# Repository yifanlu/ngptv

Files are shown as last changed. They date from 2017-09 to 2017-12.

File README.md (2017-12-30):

ngptv
=====
This is an attempt at making an HDMI adapter for the Vita. It does not work 
because the ADV7533 does not support the auto clock stopping that the Vita uses 
to save battery on the MIPI DSI clock. There are two ways of getting it to 
work.

1. Replace the ADV7533 with another part that supports MIPI clock going from 
HS to LP mode when the data lanes are not in use. There are no other DSI to 
HDMI part, but you might get away with stacking a DSI to eDP and eDP to HDMI 
for example. Another way is to use a FPGA and convert the signals manually.
2. Creating some custom part to "filter" the stopped clock to a continuous 
clock. There does not appear to be any off-the-shelf part that does this and 
I've tried looking into re-purposing jitter correctors but they don't work 
because they average out the clock signals instead of locking on to the highest 
frequency.

Both are too much work for me to consider doing, so I will leave this non-
working project as is. Included are two designs. First is ngptv, which is 
supposed to be a small board that fits inside the Vita. Due to the design 
constraints of the ADV7533 (small pitch BGA) which requires > 6 layers and the 
small size requirement of all components, it does not seem feasible for me to 
prototype (too expensive and I don't have the right equipment to assemble).
Additionally, the ADV7533 is a NDA part that requires a HDMI license to buy.

The second design is ngptv lite which is designed to connect directly to a 
[B-LCDAD-HDMI](http://www.st.com/en/development-tools/b-lcdad-hdmi1.html) 
daughterboard. This $30 board contains a ADV7533 and was originally designed to 
work with a ST evaluation board. We instead connect it to the ngptv lite which 
has a microcontroller to interface with ADV7533 as well as a redriver for MIPI 
DSI. Using a 
[FFTP-07-D-03.85-01-N](https://www.samtec.com/products/fftp-07-d-03.85-01-n) 
cable, this connects to a breakout board placed inside the Vita that brings in 
the MIPI DSI signals from the exposed testpoints. The first version lacked the 
redriver, which seemed to still work (to the extent that it works if you 
manually set the Vita's MIPI clock to not use LP mode, which breaks the on 
screen video).

These designs are provided as-is under CC 4.0.

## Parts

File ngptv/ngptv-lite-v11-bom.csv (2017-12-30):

Part | Value | Device | Package | Description
C1 | 100nf | CERAMIC-100NF-50V-10%-X7R(0603) | C0603 | 302010138
C2 | 100nf | CERAMIC-100NF-50V-10%-X7R(0603) | C0603 | 302010138
C3 | 100nf | CERAMIC-100NF-50V-10%-X7R(0603) | C0603 | 302010138
C4 | 1uf | CERAMIC-1UF-25V-10%-X7R(0603) | C0603 | 302010139
C5 | 1uf | CERAMIC-1UF-25V-10%-X7R(0603) | C0603 | 302010139
C6 | 1uf | CERAMIC-1UF-25V-10%-X7R(0603) | C0603 | 302010139
C7 | 200nF | CERAMIC-220NF-25V-10%-X7R(0603) | C0603 | 302010073
C8 | 100nf | CERAMIC-100NF-50V-10%-X7R(0603) | C0603 | 302010138
C9 | 100nf | CERAMIC-100NF-50V-10%-X7R(0603) | C0603 | 302010138
C10 | 100nf | CERAMIC-100NF-50V-10%-X7R(0603) | C0603 | 302010138
D1 | BLUE-0603 | SMD-LED-CLEAR-BLUE(0603) | LED-0603 | 304090045
J1 | FTSH-107-XX-XXX-D | FTSH-107-XX-XXX-D | FTSH-107-XX-XXX-D | 0.050X0.050" CL THROUGH HOLE TERMINAL STRIP ASSEMBLY,14PINS."
J2 | FTSH-107-XX-XXX-D | FTSH-107-XX-XXX-D | FTSH-107-XX-XXX-D | 0.050X0.050" CL THROUGH HOLE TERMINAL STRIP ASSEMBLY,14PINS."
J3 | QSH-030-01-X-D-A | QSH-030-01-X-D-A | QSH-030-01-X-D-A | HIGH SPEED SOCKET STRIP, .5mm PITCH, 60 PINS.
J4 |  | PINHD-2X3/90 | 2X03/90 | PIN HEADER
L1 | 2500R-50MA | SMD-FERRITE-BEAD-2500R-50MA(0603) | L0603 | 303030020
R1 | 2K | SMD-RES-2K-5%-1/10W(0603) | R0603 | 301010298
R2 | 2K | SMD-RES-2K-5%-1/10W(0603) | R0603 | 301010113
R3 | 2K | SMD-RES-2K-5%-1/10W(0603) | R0603 | 301010113
R4 | 200K | SMD-RES-200K-5%-1/10W(0603) | R0603 | 301010212
R5 | 2K | SMD-RES-2K-5%-1/10W(0603) | R0603 | 301010113
R6 | 2K | SMD-RES-2K-5%-1/10W(0603) | R0603 | 301010113
U1 | AP7312-1833W6-7 | AP7312 | SOT95P280X145-6N
U2 | SN75DPHY440SS | SN75DPHY440SS | RHR0028A_NV
U3 | ATTINY24A-SSU | ATTINY24A-SSU | SOIC127P600X175-14N | 8-bit Microcontroller with In-System Programmable Flash
U4 | PCA9306_DCT_8 | PCA9306_DCT_8 | DCT8
X1 | ZX62D-B-5PA8 | ZX62D-B-5PA8 | ZX62D-B-5PA8 | Micro USB Type B Connector - Standard, Shell Through Hole

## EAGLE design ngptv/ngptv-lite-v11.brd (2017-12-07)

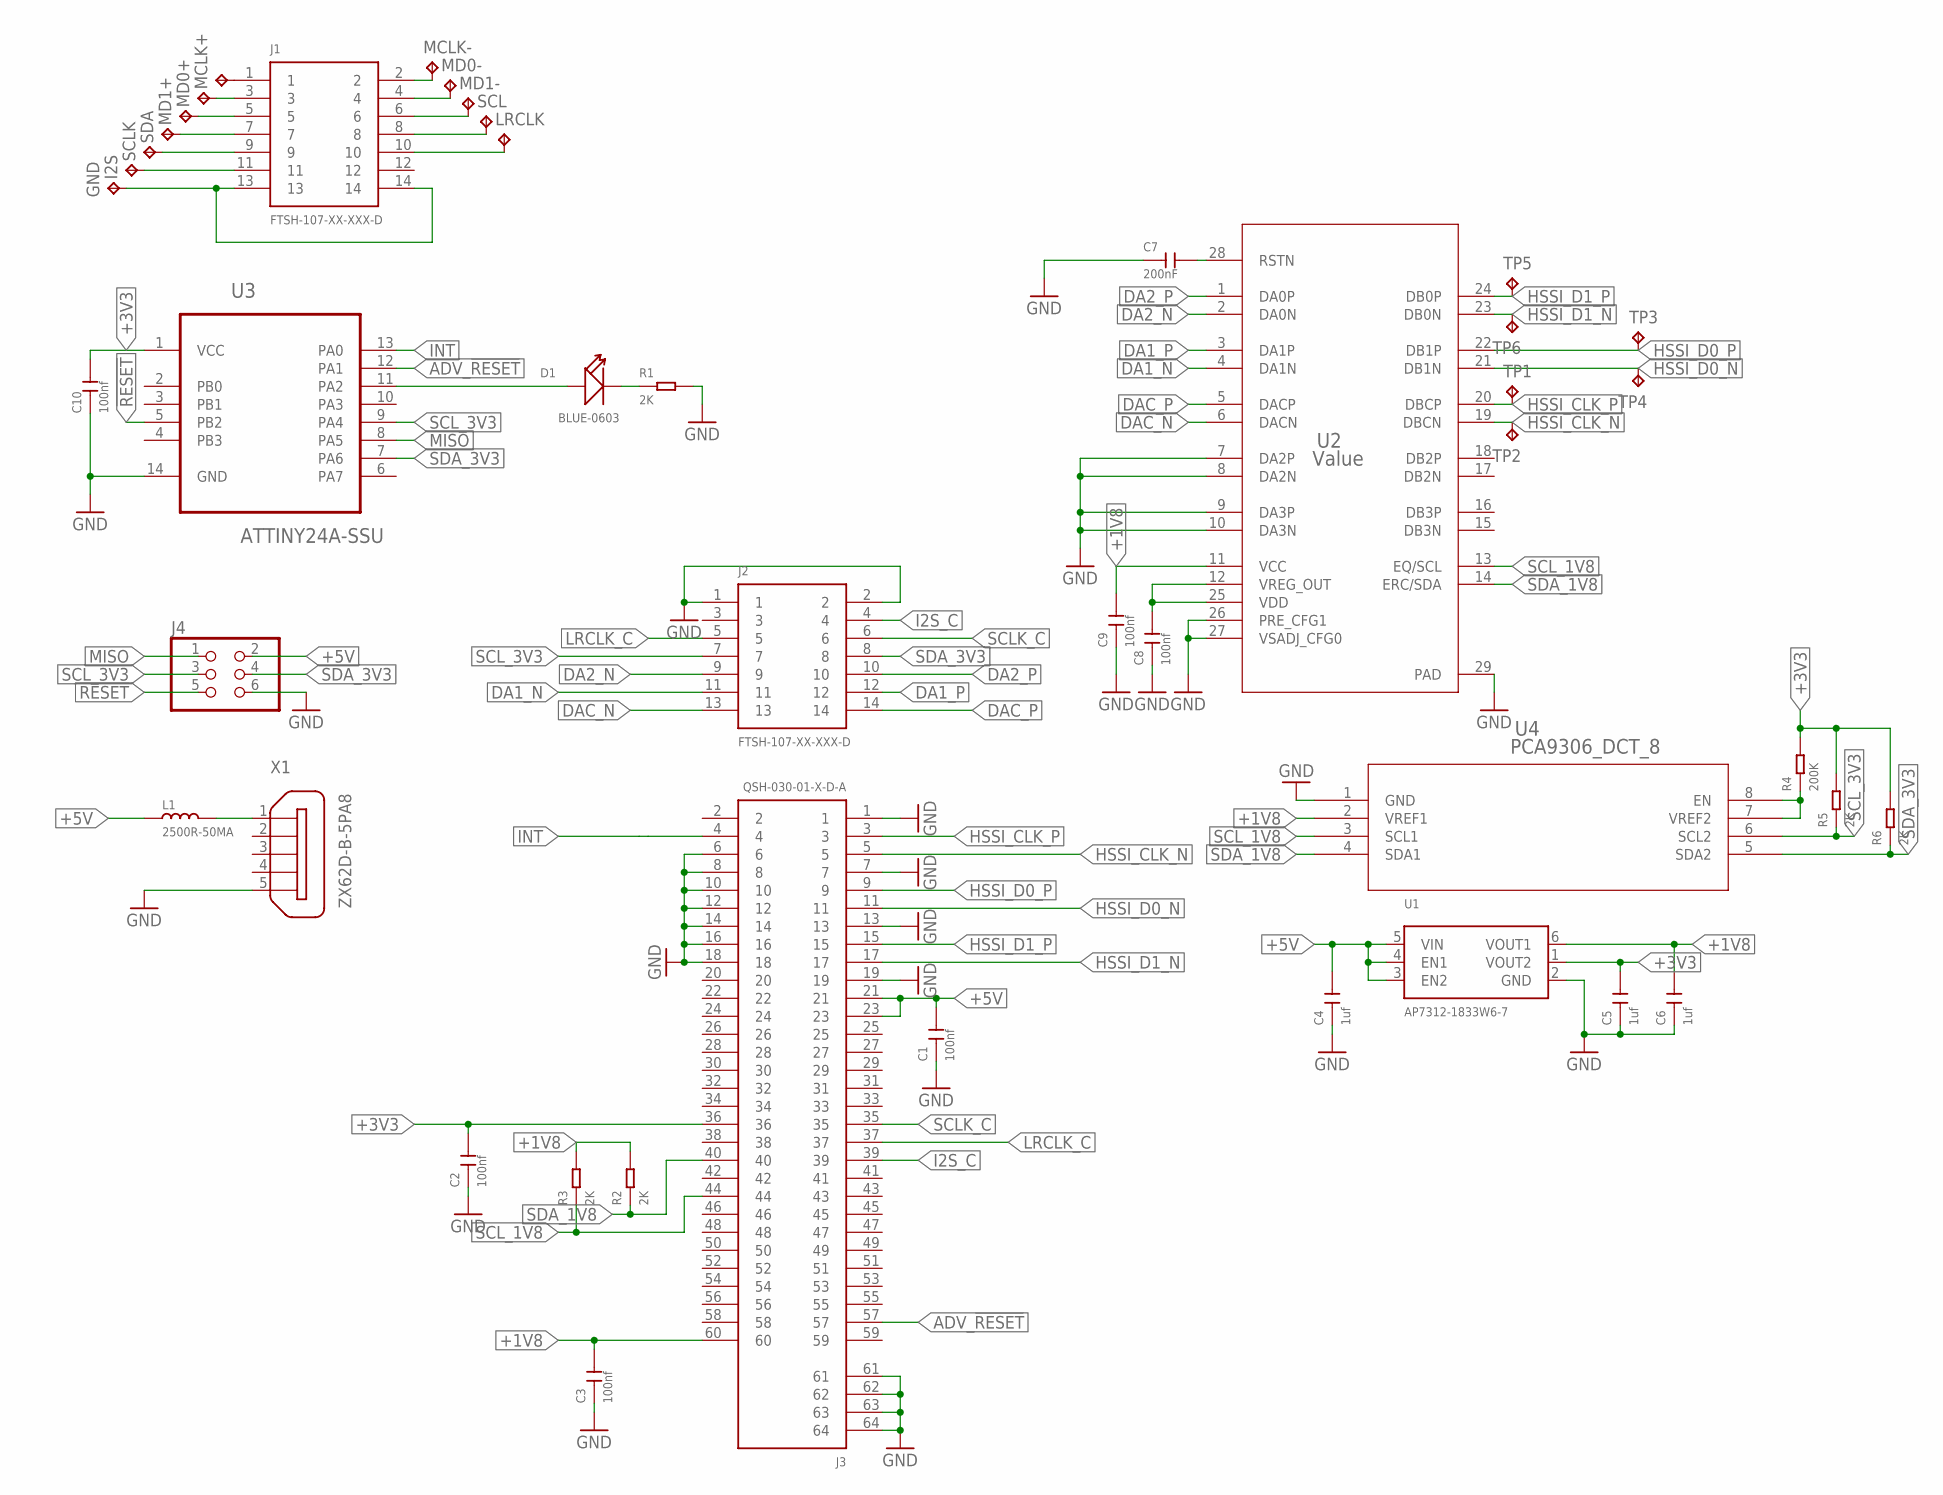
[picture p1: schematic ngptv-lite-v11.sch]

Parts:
C1, C2, C3, C8, C9, C10: 100nf; C0603
C4, C5, C6: 1uf; C0603
C7: 200nF; C0603
D1: BLUE-0603; LED-0603
GND: TPTP14R; TP14R
I2S: TPTP12R; TP12R
J1, J2: FTSH-107-XX-XXX-D
J3: QSH-030-01-X-D-A
J4: PINHD-2X3/90; 2X03/90
L1: 2500R-50MA; L0603
LRCLK: TPTP12R; TP12R
MCLK+: TPTP12R; TP12R
MCLK-: TPTP12R; TP12R
MD0+, MD0-, MD1+, MD1-: TPTP12R; TP12R
R1, R2, R3, R5, R6: 2K; R0603
R4: 200K; R0603
SCL: TPTP12R; TP12R
SCLK: TPTP12R; TP12R
SDA: TPTP12R; TP12R
TP1, TP2, TP3, TP4, TP5, TP6: TPTP06SQ; TP06SQ
U1: AP7312-1833W6-7; SOT95P280X145-6N
U2: Value; RHR0028A_NV
U3: ATTINY24A-SSU; SOIC127P600X175-14N
U4: PCA9306_DCT_8; DCT8
X1: ZX62D-B-5PA8

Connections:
!RESET: J4.5, U3.5 (PB2)
+1V8: C3.2, C6.2, C9.2, J3.60, R2.2, R3.2, U1.6 (VOUT1), U2.11 (VCC), U4.2 (VREF1)
+3V3: C2.2, C5.2, C10.2, J3.36, R4.2, R5.2, R6.2, U1.1 (VOUT2), U3.1 (VCC)
+5V: C1.2, C4.2, J3.21, J3.23, J4.2, L1.1, U1.3 (EN2), U1.4 (EN1), U1.5 (VIN)
ADV_!RESET: J3.57, U3.12 (PA1)
DA1_N: J2.11, U2.4 (DA1N)
DA1_P: J2.12, U2.3 (DA1P)
DA2_N: J2.9, U2.2 (DA0N)
DA2_P: J2.10, U2.1 (DA0P)
DAC_N: J2.13, U2.6 (DACN)
DAC_P: J2.14, U2.5 (DACP)
GND: C1.1, C2.1, C3.1, C4.1, C5.1, C6.1, C7.1, C8.1, C9.1, C10.1, J2.1, J2.2, J3.1, J3.6, J3.7, J3.8, J3.10, J3.12, J3.13, J3.14, J3.16, J3.18, J3.19, J3.61, J3.62, J3.63, J3.64, J4.6, R1.2, U1.2 (GND), U2.7 (DA2P), U2.8 (DA2N), U2.9 (DA3P), U2.10 (DA3N), U2.26 (PRE_CFG1), U2.27 (VSADJ_CFG0), U2.29 (PAD), U3.14 (GND), U4.1 (GND), X1.5
GND_H: GND.TP, J1.13, J1.14
HSSI_CLK_N: J3.5, TP2.TP, U2.19 (DBCN)
HSSI_CLK_P: J3.3, TP1.TP, U2.20 (DBCP)
HSSI_D0_N: J3.11, TP4.TP, U2.21 (DB1N)
HSSI_D0_P: J3.9, TP3.TP, U2.22 (DB1P)
HSSI_D1_N: J3.17, TP6.TP, U2.23 (DB0N)
HSSI_D1_P: J3.15, TP5.TP, U2.24 (DB0P)
I2S: I2S.TP, J1.11
I2S_C: J2.4, J3.39
INT: J3.4, U3.13 (PA0)
LRCLK: J1.10, LRCLK.TP
LRCLK_C: J2.5, J3.37
MCLK_N: J1.2, MCLK-.TP
MCLK_P: J1.1, MCLK+.TP
MD0_N: J1.4, MD0-.TP
MD0_P: J1.3, MD0+.TP
MD1_N: J1.6, MD1-.TP
MD1_P: J1.5, MD1+.TP
MISO: J4.1, U3.8 (PA5)
SCL: J1.8, SCL.TP
SCLK: J1.9, SCLK.TP
SCLK_C: J2.6, J3.35
SCL_1V8: J3.44, R3.1, U2.13 (EQ/SCL), U4.3 (SCL1)
SCL_3V3: J2.7, J4.3, R5.1, U3.9 (PA4), U4.6 (SCL2)
SDA: J1.7, SDA.TP
SDA_1V8: J3.40, R2.1, U2.14 (ERC/SDA), U4.4 (SDA1)
SDA_3V3: J2.8, J4.4, R6.1, U3.7 (PA6), U4.5 (SDA2)
STATUS: D1.+, U3.11 (PA2)
STATUS_N: D1.-, R1.1
TI_!RESET: C7.2, U2.28 (RSTN)
USB_VBUS: L1.2, X1.1
VREF2: R4.1, U4.7 (VREF2), U4.8 (EN)
VREG_OUT: C8.2, U2.12 (VREG_OUT), U2.25 (VDD)

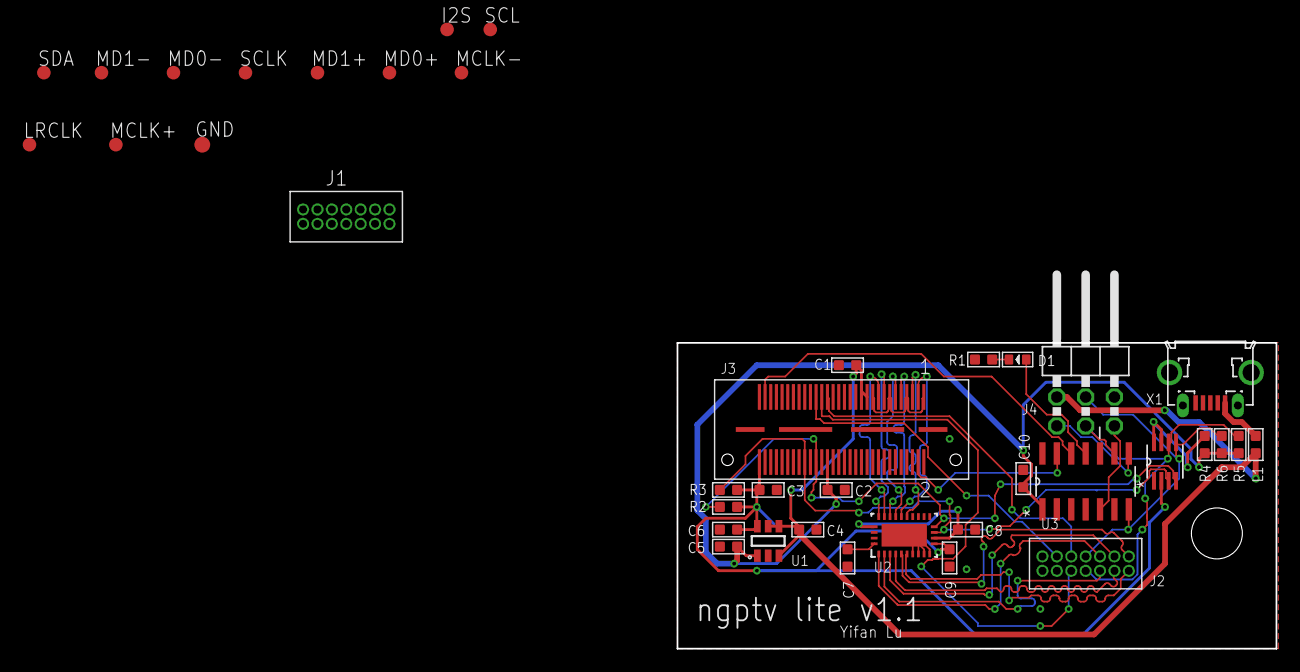
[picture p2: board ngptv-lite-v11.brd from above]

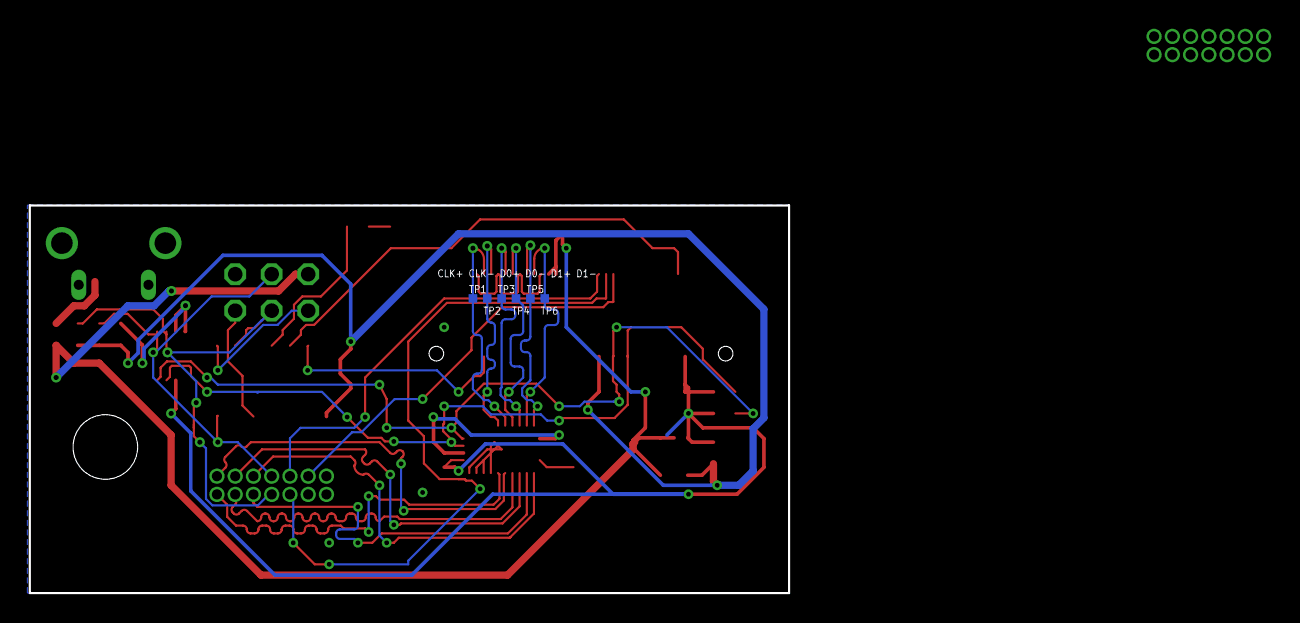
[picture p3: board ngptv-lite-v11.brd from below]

Board: 2 copper layers, 52.8 x 27.0 mm, 45 parts (6 on the bottom side), 45 nets.

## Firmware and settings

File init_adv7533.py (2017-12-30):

#!/usr/bin/python

# Sequence from https://github.com/xerpi/vita-baremetal-sample/blob/master/src/hdmi.c

import smbus

HDMI_I2C_BUS = 1
HDMI_I2C_ADDR = 0x7A

# Configurable addresses
HDMI_I2C_CEC_ADDR = 0x78

# ADV7533 Main registers
ADV7533_REG_PACKET_ENABLE0 = 0x40
ADV7533_REG_POWER = 0x41
ADV7533_REG_STATUS = 0x42
ADV7533_REG_AVI_INFOFRAME_1 = 0x56
ADV7533_REG_INT_1 = 0x97
ADV7533_REG_HDCP_HDMI_CFG = 0xAF
ADV7533_REG_CEC_I2C_ADDR = 0xE1
ADV7533_REG_POWER2 = 0xD6

ADV7533_PACKET_ENABLE_GC = 0x80

ADV7533_POWER_POWER_DOWN = 0x40

ADV7533_INT1_BKSV = 0x40

ADV7533_STATUS_HPD = 0x40

ADV7533_REG_POWER2_HPD_SRC_MASK = 0xC0
ADV7533_REG_POWER2_HPD_SRC_HPD = 0x40

# ADV7533 CEC registers
ADV7533_REG_CEC_DSI_INTERNAL_TIMING = 0x27

LANES = 2
CLOCK_DIV_BY_LANES = [6, 4, 3]

def hdmi_write(bus, addr, reg, data):
  bus.write_byte_data(addr>>1, reg, data)

def hdmi_read(bus, addr, reg):
  return bus.read_byte_data(addr>>1, reg)

def hdmi_set_bit(bus, addr, reg, bit):
  val = hdmi_read(bus, addr, reg)
  val |= bit
  hdmi_write(bus, addr, reg, val)

def hdmi_clr_bit(bus, addr, reg, bit):
  val = hdmi_read(bus, addr, reg)
  val &= ~bit
  hdmi_write(bus, addr, reg, val)

def hdmi_update_bits(bus, addr, reg, mask, val):
  data = hdmi_read(bus, addr, reg)
  data &= ~mask
  data |= val & mask
  hdmi_write(bus, addr, reg, data)

def main(bus, test, hdcp):
  print "Setting up CEC address"
  hdmi_write(bus, HDMI_I2C_ADDR, ADV7533_REG_CEC_I2C_ADDR, HDMI_I2C_CEC_ADDR)

  print "Waiting for HDMI hot-plug detect"
  while True:
    status = hdmi_read(bus, HDMI_I2C_ADDR, ADV7533_REG_STATUS)
    if ((status & ADV7533_STATUS_HPD) != 0):
      break

  print "Powering up ADV7533"
  hdmi_update_bits(bus, HDMI_I2C_ADDR, ADV7533_REG_POWER, ADV7533_POWER_POWER_DOWN, 0)
  hdmi_update_bits(bus, HDMI_I2C_ADDR, ADV7533_REG_POWER2, ADV7533_REG_POWER2_HPD_SRC_MASK, ADV7533_REG_POWER2_HPD_SRC_HPD)

  print "Sending main config sequence"
  hdmi_write(bus, HDMI_I2C_ADDR, 0x16, 0x20)
  hdmi_write(bus, HDMI_I2C_ADDR, 0x9a, 0xe0)
  hdmi_write(bus, HDMI_I2C_ADDR, 0xba, 0x70)
  hdmi_write(bus, HDMI_I2C_ADDR, 0xde, 0x82)
  hdmi_write(bus, HDMI_I2C_ADDR, 0xe4, 0x40)
  hdmi_write(bus, HDMI_I2C_ADDR, 0xe5, 0x80)

  print "Sending CEC config sequence"
  hdmi_write(bus, HDMI_I2C_CEC_ADDR, 0x15, 0xd0)
  hdmi_write(bus, HDMI_I2C_CEC_ADDR, 0x17, 0xd0)
  hdmi_write(bus, HDMI_I2C_CEC_ADDR, 0x24, 0x20)
  hdmi_write(bus, HDMI_I2C_CEC_ADDR, 0x57, 0x11)
  hdmi_write(bus, HDMI_I2C_CEC_ADDR, 0x05, 0xc8)

  print "Set number of dsi lanes"
  hdmi_write(bus, HDMI_I2C_CEC_ADDR, 0x1C, LANES << 4)

  if (test):
    print "Set pixel clock auto mode"
    hdmi_write(bus, HDMI_I2C_CEC_ADDR, 0x16, 0x00)
  else:
    print "Set pixel clock divider mode"
    hdmi_write(bus, HDMI_I2C_CEC_ADDR, 0x16, CLOCK_DIV_BY_LANES[LANES - 2] << 3)

  if (test):
    htotal, vtotal, hfp, hsw, hbp, vfp, vsw, vbp = 0x672, 0x2EE, 0x6E,  0x28,  0xDC, 5,   5, 0x14;

    print "Horizontal porch params"
    hdmi_write(bus, HDMI_I2C_CEC_ADDR, 0x28, htotal >> 4);
    hdmi_write(bus, HDMI_I2C_CEC_ADDR, 0x29, (htotal << 4) & 0xff);
    hdmi_write(bus, HDMI_I2C_CEC_ADDR, 0x2a, hsw >> 4);
    hdmi_write(bus, HDMI_I2C_CEC_ADDR, 0x2b, (hsw << 4) & 0xff);
    hdmi_write(bus, HDMI_I2C_CEC_ADDR, 0x2c, hfp >> 4);
    hdmi_write(bus, HDMI_I2C_CEC_ADDR, 0x2d, (hfp << 4) & 0xff);
    hdmi_write(bus, HDMI_I2C_CEC_ADDR, 0x2e, hbp >> 4);
    hdmi_write(bus, HDMI_I2C_CEC_ADDR, 0x2f, (hbp << 4) & 0xff);

    print "Vertical porch params"
    hdmi_write(bus, HDMI_I2C_CEC_ADDR, 0x30, vtotal >> 4);
    hdmi_write(bus, HDMI_I2C_CEC_ADDR, 0x31, (vtotal << 4) & 0xff);
    hdmi_write(bus, HDMI_I2C_CEC_ADDR, 0x32, vsw >> 4);
    hdmi_write(bus, HDMI_I2C_CEC_ADDR, 0x33, (vsw << 4) & 0xff);
    hdmi_write(bus, HDMI_I2C_CEC_ADDR, 0x34, vfp >> 4);
    hdmi_write(bus, HDMI_I2C_CEC_ADDR, 0x35, (vfp << 4) & 0xff);
    hdmi_write(bus, HDMI_I2C_CEC_ADDR, 0x36, vbp >> 4);
    hdmi_write(bus, HDMI_I2C_CEC_ADDR, 0x37, (vbp << 4) & 0xff);

    print "Enable internal timing generator"
    hdmi_write(bus, HDMI_I2C_CEC_ADDR, ADV7533_REG_CEC_DSI_INTERNAL_TIMING, 0xCB)
    hdmi_write(bus, HDMI_I2C_CEC_ADDR, ADV7533_REG_CEC_DSI_INTERNAL_TIMING, 0x8B)
    hdmi_write(bus, HDMI_I2C_CEC_ADDR, ADV7533_REG_CEC_DSI_INTERNAL_TIMING, 0xCB)
  else:
    print "Disable internal timing generator"
    hdmi_write(bus, HDMI_I2C_CEC_ADDR, ADV7533_REG_CEC_DSI_INTERNAL_TIMING, 0x0B)

  print "GC Packet Enable"
  hdmi_write(bus, HDMI_I2C_ADDR, ADV7533_REG_PACKET_ENABLE0, ADV7533_PACKET_ENABLE_GC)

  print "Down Dither Output Colour Depth - 8 Bit (default)"
  hdmi_write(bus, HDMI_I2C_ADDR, 0x49, 0x00)

  print "Set HDMI/DVI Mode Select = HDMI Mode Enabled - bit 1"
  hdmi_set_bit(bus, HDMI_I2C_ADDR, ADV7533_REG_HDCP_HDMI_CFG, 0x2)

  print "Set Color Depth to 24 Bits/Pixel"
  hdmi_clr_bit(bus, HDMI_I2C_ADDR, 0x4C, 0x0F)
  hdmi_set_bit(bus, HDMI_I2C_ADDR, 0x4C, 0x04)

  print "Set Active Format Aspect Ratio = 16:9 (Center)"
  hdmi_clr_bit(bus, HDMI_I2C_ADDR, ADV7533_REG_AVI_INFOFRAME_1, 0x1F)
  hdmi_set_bit(bus, HDMI_I2C_ADDR, ADV7533_REG_AVI_INFOFRAME_1, 0x2A)

  print "Set V1P2 Enable"
  hdmi_set_bit(bus, HDMI_I2C_ADDR, 0xE4, 0xC0)

  if (test):
    print "Enable test mode"
    hdmi_write(bus, HDMI_I2C_CEC_ADDR, 0x55, 0x80)
  else:
    print "Disable test mode"
    hdmi_clr_bit(bus, HDMI_I2C_CEC_ADDR, 0x55, 0x00)

  print "Enable hdmi"
  hdmi_write(bus, HDMI_I2C_CEC_ADDR, 0x03, 0x89)

  if (hdcp):
    print "Set HDCP"
    hdmi_write(bus, HDMI_I2C_ADDR, ADV7533_REG_HDCP_HDMI_CFG, 0x96)

    print "Wait for the BKSV flag"
    while True:
      status = hdmi_read(bus, HDMI_I2C_ADDR, ADV7533_REG_INT_1)
      if ((status & ADV7533_INT1_BKSV) != 0):
        break

    print "Clear BKSV interrupt"
    hdmi_write(bus, HDMI_I2C_ADDR, ADV7533_REG_INT_1, (status & ~0xBF) | ADV7533_INT1_BKSV)

  print "Done."

def init(bus):
  print "Setting up CEC address"
  hdmi_write(bus, HDMI_I2C_ADDR, ADV7533_REG_CEC_I2C_ADDR, HDMI_I2C_CEC_ADDR)

def configure(bus, lanes):
  # ADV7533 Power Settings
  print "Power down"
  hdmi_clr_bit(bus, HDMI_I2C_ADDR, 0x41, 0x40)
  print "HPD Override"
  hdmi_set_bit(bus, HDMI_I2C_ADDR, 0xD6, 0xc0)
  print "Gate DSI LP Oscillator and DSI Bias Clock Powerdown"
  hdmi_clr_bit(bus, HDMI_I2C_CEC_ADDR, 0x03, 0x02)
  
  print "Fixed registers that must be set on power-up"
  hdmi_update_bits(bus, HDMI_I2C_ADDR, 0x16, 0x3E, 0x20)
  hdmi_write(bus, HDMI_I2C_ADDR, 0x9A, 0xE0)
  hdmi_update_bits(bus, HDMI_I2C_ADDR, 0xBA, 0xF8, 0x70)
  hdmi_write(bus, HDMI_I2C_ADDR, 0xDE, 0x82)
  
  hdmi_set_bit(bus, HDMI_I2C_ADDR, 0xE4, 0x40)
  hdmi_write(bus, HDMI_I2C_ADDR, 0xE5, 0x80)
  
  hdmi_update_bits(bus, HDMI_I2C_CEC_ADDR, 0x15, 0x30, 0x10)
  hdmi_update_bits(bus, HDMI_I2C_CEC_ADDR, 0x17, 0xF0, 0xD0)
  hdmi_clr_bit(bus, HDMI_I2C_CEC_ADDR, 0x24, 0x10)
  hdmi_set_bit(bus, HDMI_I2C_CEC_ADDR, 0x57, 0x10 | 0x01)
  
  print "Configure the number of DSI lanes"
  hdmi_write(bus, HDMI_I2C_CEC_ADDR, 0x1C, (lanes << 4))
  
  # Setup video output mode
  print "Select HDMI mode"
  hdmi_set_bit(bus, HDMI_I2C_ADDR, 0xAF, 0x02)
  print "HDMI Output Enable"
  hdmi_set_bit(bus, HDMI_I2C_CEC_ADDR, 0x03, 0x80)

  print "GC packet enable"
  hdmi_set_bit(bus, HDMI_I2C_ADDR, 0x40, 0x80)
  print "Input color depth 24-bit per pixel"
  hdmi_update_bits(bus, HDMI_I2C_ADDR, 0x4C, 0x0F, 0x03)
  print "Down dither output color depth"
  hdmi_write(bus, HDMI_I2C_ADDR, 0x49, 0xfc)
  
  print "Internal timing disabled"
  hdmi_clr_bit(bus, HDMI_I2C_CEC_ADDR, 0x27, 0x80)

def show_test_pattern(bus):
  print "Set test pattern"
  hdmi_set_bit(bus, HDMI_I2C_CEC_ADDR, 0x55, 0x80)
  hdmi_set_bit(bus, HDMI_I2C_CEC_ADDR, 0x55, 0xA0)
  print "HDMI Output Enable"
  hdmi_set_bit(bus, HDMI_I2C_CEC_ADDR, 0x03, 0x89)
  print "Select HDMI mode"
  hdmi_set_bit(bus, HDMI_I2C_ADDR, 0xAF, 0x16)

def setup_audio(bus):
  print "HDMI Startup"
  n_value = 6144;
  temp_byte = ((n_value&0xF0000)>>16) & 0xFF
  hdmi_write(bus, HDMI_I2C_ADDR, 0x1, temp_byte);

  temp_byte = ((n_value&0xFF00)>>8) & 0xFF
  hdmi_write(bus, HDMI_I2C_ADDR, 0x2, temp_byte);

  temp_byte = (n_value&0xFF) & 0xFF
  hdmi_write(bus, HDMI_I2C_ADDR, 0x3, temp_byte);

  print "Set SPDIF Enable = SPDIF Enabled"
  hdmi_set_bit(bus, HDMI_I2C_ADDR, 0x0B, 0x80);

  print "Set I2S Enable = I2S Enabled"
  hdmi_set_bit(bus, HDMI_I2C_ADDR, 0x0C, 0x04);

  print "Set I2S Sampling Frequency = 48.0 kHz is 0x20, 44.1Khz is 0x0"
  hdmi_write(bus, HDMI_I2C_ADDR, 0x15, 0x0);

  print "Set Audio Select = SPDIF Input is 0x10, I2S is 0x0"
  hdmi_set_bit(bus, HDMI_I2C_ADDR, 0x0A, 0x00);

def power_up(bus):
  print "Power up"
  hdmi_clr_bit(bus, HDMI_I2C_ADDR, 0x41, 0x40)

if __name__ == "__main__":
  bus = smbus.SMBus(HDMI_I2C_BUS)
  main(bus, 0, 1)
  #init(bus)
  #configure(bus, 2)
  #show_test_pattern(bus)
  #setup_audio(bus)
  #power_up(bus)

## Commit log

2017-09-18 Finished schematic
    [ngptv.sch]
2017-09-27 Updated sch
    [ngptv.sch]
2017-09-27 Added lite version
    [ngptv-lite.brd, ngptv-lite.sch]
2017-12-07 ngptv lite v1.1 design
    [ngptv-lite-v11.brd, ngptv-lite-v11.sch]
2017-12-07 Minor modifications for fab
    [ngptv-lite-v11.brd]
2017-12-30 Added BOM
    [ngptv-lite-v11-bom.csv]

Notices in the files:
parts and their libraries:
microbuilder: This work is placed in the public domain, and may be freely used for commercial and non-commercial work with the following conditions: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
